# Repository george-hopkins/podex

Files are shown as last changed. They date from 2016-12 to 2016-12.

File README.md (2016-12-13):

# podex

**podex** is an AVR-based BDM interface for 68HC12 processors.

## Documentation

 * [Introduction](./docs/introduction.md)
 * [Hardware](./docs/hardware.md)
 * [Debugging with GDB](./docs/gdb.md)
 * [Demo Application](./docs/demo.md)
 * [FAQ](./docs/faq.md)

## Authors

 * Marek Peca <marek@duch.cz>

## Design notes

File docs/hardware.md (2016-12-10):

# Hardware

## Schematics

To connect a wire on one side and RS232 on the other to the MCU is almost as difficult as to connect a bulb to battery in a torch.

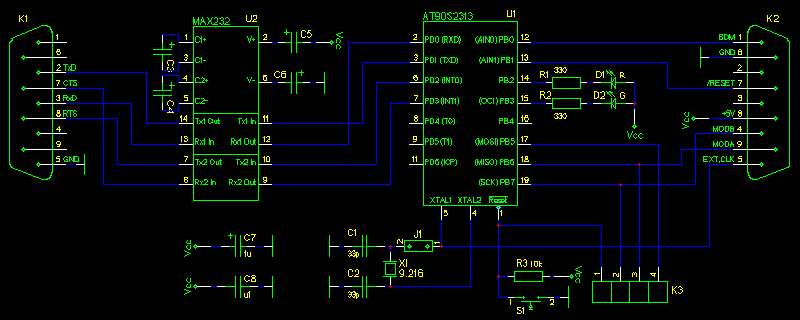
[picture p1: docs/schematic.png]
Schematic


RS232 signals TxD, RxD, RTS, CTS (in schematics marked from podex' point of view) are connected to AVR MCU via buffer U2, MAX232. In prototype, there has been used "worse" variant MAX232 (no A suffix), which may require 1uF capacitors around it (on PCB the size 1206 was chosen). They can be tantalum, but they are also available in ceramic with this capacity (wow, that progress... on Taiwan they are really working hard). Connector K1 can be plugged directly to the COM-port of IBM PC. LEDs D1, D2 acts as indicators of activity and error state and also can be controlled by software of control computer. There are signals MOSI, MISO and SCK of serial programming interface of AVR and its /RESET signal available on connector K3, which serve (together with GND potential from K1 or K2) as an interface for programming FLASH of AVR by podex firmware. PCB allows connecting a switch S1 for resetting AVR, but this shouldn't be needed. Clock for AVR is obtained from crystal X1 with the most desirable frequency of 9.216MHz -- maximal supported rate for 5V AT90S2313 is 10MHz and 9.216MHz is the nearest lower rate, which allows precise division to 115200b/s serial transfer. Crystal is connected through point J1, which should be disconnected and then get clock from external source via connector K2, for example from EClock signal of HC12 CPU. Connector K2 is to be connected to BDM, and among this external clock contains three-state signal BDM(BKGD), signal /RESET and software controlled lines MODA, MODB, allowing use of extended memory (bus) of HC12 CPU.

## Construction

Podex has been designed on two-sided PCB with SMD components mounted on both sides. The most narrow distance between conductors is ca. 0.2mm, but some very kind people at [one PCB laboratory](www.fm.tul.cz/en/departmens/institute-of-information-technology-and-electronics/structure/pcb-lab), which officialy supports only spaces greater than 0.25mm, made boards of podex in a perfect quality. Board has to be put to a cover of two connectors Canon DB9. It is placed between pins of these connectors and surface soldered to these pins (which are ordinary used for soldering with cable wires). Connectors are used this way to hold a board in position. Connector K1 is female, according to RS232 connection, K2 is male to avoid their swapping. LEDs are round with 3mm diameter, if they will be used, it would be very nice to drill holes for them in a cover. As a programming connector K3 I have used SIL (single-in-line) sockets, available as a line, which can be broken to smaller pieces. Pay attention for this component not to be too much thick to fit in a cover. J1 can be hardly connected by a wire, if you won't use external clock (otherwise, let it disconnected). You will probably never need a S1 switch. If you can't use PCB of this layout or you can't order fabrication of it, you can build the circuit on a universal PCB -- it is very simple.

### Printed Circuit Board

#### PCB (Top Layer)

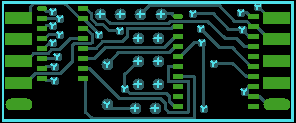
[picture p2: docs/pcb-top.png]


#### PCB (Bottom Layer)

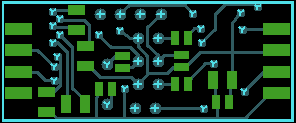
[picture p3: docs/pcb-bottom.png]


#### Components (Top Layer)

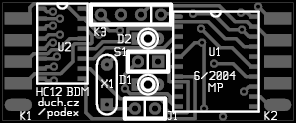
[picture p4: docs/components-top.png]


#### Components (Bottom Layer)

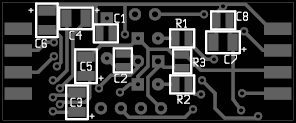
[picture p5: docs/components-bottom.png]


### List of Components

| Parts | Description | Package | Value |
|---|---|---|---|
| U1 | AT90S2313 | SO20W | |
| U2 | MAX232 | SO16 | |
| K1, K2 | DB9 | DB9SM | |
| D1 | LED | LED_3mm | R |
| D2 | LED | LED_3mm | G |
| C1, C2 | CAPACITOR | 0805 | 33p |
| C8 | CAPACITOR | 0805 | u1 |
| R1, R2 | RESISTOR | 0805 | 330 |
| R3 | RESISTOR | 805 | 10k |
| S1 | SWITCH_PUSHBUTTON_NO | JUMPER2 | |
| X1 | CRYSTAL | HC49 | 9.216MHz |
| J1 | JUMPER | JUMPER2 | |
| C3, C4, C5, C6, C7 | CAPACITOR | 1206 | 1u |
| K3 | HEADER3 | JUMPER4 | |

Podex box is connected to control computer by direct plugging it to RS232 DB9 connector or by a cable, which must contain signals RTS and CTS. For BDM interface, there is a standardized 6pin connector, recommended by HC12 documentation, for use of lines MODA, MODB there is its 10pin extension. Pinout of K2 connector is chosen to allow direct interconnection of self-cutting DB9 connector on the podex side and 6(10)pin self-cutting connector PFL on the other side of AWG cable.

BDM connectors connection

## Firmware Flashing

Firmware is loaded to FLASH of AVR AT90S2313 via connector K3. For this it is sufficient to connect serial programming interface signals to parallel interface LPT/Centronics according to following schematic, widely used in AVR community and known as a "Direct AVR Parallel Access":

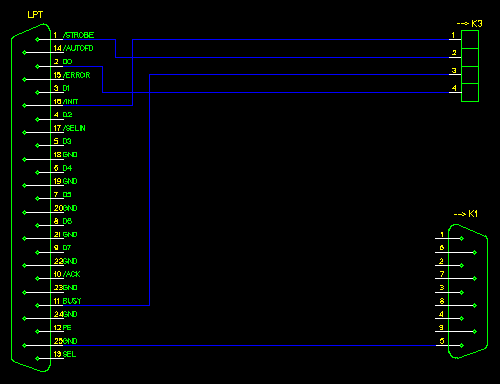
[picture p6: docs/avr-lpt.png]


Attention, there should be also connected a ground of podex (GND) to a control computer during programing, using a connector K1. Also it is needed to power flashed podex by 5V source via K2 connector (it is possible to power it from a HC12 board, if there aren't used lines MODA, MODB).

With above mentioned parallel port connection there can be used e.g. flashing software [uisp](http://www.nongnu.org/uisp/). The firmware is then loaded e.g. by the following command:

```bash
uisp -dlpt=0x378 -dprog=dapa --erase --upload --verify if=podex.hex -v=3 --hash=12
```

(0x378 is LPT base address, podex.hex is filename of the firmware, for more see uisp docs.) After loading of firmware the podex is finished and ready to operate with HC12.

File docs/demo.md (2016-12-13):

# Demo Application

As a very little demonstration of podex use, a small program in C is included which displays eightbit moving light ("snake"), and guide how to compile it, load to RAM or FLASH and debug. The program expects that there are eight lights connected to port PH (switched on by level H). It has been tested on a board with M68HC912D60A.

At the beggining, source includes definition file `intvec.h`, where is defined data structure interrupt_vectors, copied from [a post](https://groups.yahoo.com/neo/groups/gnu-m68hc11/conversations/topics/4010) in a mailing list. Only one entry in this structure is used -- start of the program (`_start` is the very beggining of compiled program). If the program would use some interrupt handlers, their names should be added to this structure. This structure is inserted to a linker section called `.vectors`, which is on the end of memory address space, starting with address 0xff00, where HC12 looks for hardware event handler pointers. Who knows GNU ld well, he will perhaps find my strange solution fool, so, please, excuse me.

Follow a definition of I/O space constant pointers DDRH and PORTH, ie. control registers of output port, which has to be attached to lights. Function `sleep()` does a delay by thousands repetitions of nothing to get a speed of snake's motion reasonable. The eternal loop of main program contains no magic, only a very weird expression of rotation of eight bits, which isn't (at least in current version) optimized to a rotation instruction by gcc, what a wonder, gcc places this ugly thing in output verbatim. If anybody suffers from this, there is no problem to insert a piece of assembler in source.

In the case of execution from FLASH (ie. automatically after reset or power on) there is redefined the `__premain` function, which is called before first function call, so it means before call of `main()`. In this function, there is on the first place disabled an evil watchdog COP, because some HC12's are buggy and need this to not to be stopped by it. But mainly, there is remapped RAM memory from original location at 0x000 (which isn't very handy, because it's overlapped with control registers) to new address 0x800 and then the stack pointer is moved by the same distance to point to newly located RAM and not to the hole at old location.

Linker ld should know, in which address range should the result reside, it is possible to specify this by a so called ld-script. For operation with RAM only, there has been created script `ram.x`, for placement of program to FLASH there is a script `flash.x`. Compilation is exeuted using Makefile.

If you want the program to be in FLASH, to be run automatically after HC12 reset, you can execute:

```bash
make FLASH=
m68hc12-gdb snake.elf
# (gdb) target bdm12 ttyS0 4 0x0 0x800 0xd00 0x8000
# (gdb) load snake.elf
```

If you'd like to load the program to RAM and debug it a little bit, you can execute:

```bash
make
m68hc12-gdb snake.elf
# (gdb) target bdm12 ...
```

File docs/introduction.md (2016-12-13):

# Introduction

## What is BDM of Motorola HC12?

BDM (background debugging mode) of Motorola 68HC12 processors is

 * special CPU mode, in which is possible to intervene in a program execution, to read and write memory and registers, debug the program (set breakpoints, watchpoints, step)
 * interface of HC12 CPU, which is used to control BDM mode (from another computer)

The BDM interface is used either for HC12 microcontroller program debugging as for programming of their FLASH memories. BDM is the most convenient way to program internal FLASH memory of HC12, but it is also able to program external memories, which are found eg. on some development boards.

BDM, used in Motorola HC12 CPU's, is implemented only in this processor family. There is a different interface, called also BDM, and offering similar functionality, implemented in Motorola 32bit MCU series 68300. Other similar, but more general interface, used by many vendors either for processors and microcontrollers, as in programmable logic devices and memories, is JTAG.

## What is podex (BDM pod)?

Our podex is an interface (physical, ie. a box, circuit -- called "pod"), interconnecting BDM of HC12 CPU with another computer, from which is the HC12 programmed and debugged. One side of podex is connected to BDM interface (standard 6pin or extended 10pin connector) and other side of podex to RS232 serial interface of control computer. It also works well with USB-RS232 converter and should work also with other computers, than Intel/IBM PC.

Schematics, directions for assembly and use, firmware for MCU contained in podex, are here offered for free public use. Cost of components (at least in the Czech republic, but they are anyway all manufactured in Asia) is about 5EUR (and it's still dropping...).

In a stage of podex development, I have heard of only two pods, which have had schematics publicly available:

 * Malte Avenhuse's pod, which creator also have published its firmware of MCU; this pod, however, isn't supported by any debugger
 * Kevin Ross' pod, which is commercial, but sold as a kit; it was the only pod beside Malte Avenhaus', which has had published a communication protocol and which is also supported by two commercial debuggers and by GNU gdb

Podex has been designed to be protocol-compatible with pod of Kevin Ross. The main goal was to develop a cheap and freely available BDM pod, which will be able to operate with GNU gdb debugger. I consider it's better to implement the Kevin Ross' protocol (even it's somehow thick-skulled), for which is GNU gdb already ported (and to improve this port and profit from wider user base), than to invent another, functionally the same, protocol, and put redundant support code for almost the same thing to gdb.

Podex interconnects one-wire bidirectional BDM interface (which requires pretty precise timing and so it cannot be implemented only in software without keeping some important time delays exact) with serial line of control computer. The main part of communication on the line is only passed over by pode between serial line and BDM, the rest of communication on the side of control computer are some service commands, such as time constant of BDM setting (according to HC12 frequency) or controlling of HC12 RESET line, also connected to podex. Podex is based on Atmel AVR MCU, in presented circuit with particular AT90S2313. Use of MCU as a BDM interface controller (as opposite to eg. gate array) implies, unfortunately, the BDM interface speed limit (what means limit of connected HC12's frequency).

## Where can I use podex?

Podex is able to operate with BDM of all microcomputers, boards and devices, based on Motorola HC12 or HCS12 core, which have

 * frequency of BDM (which is a half of clock rate) up to approximately the frequency of used AVR in podex; in presented circuit with 9.216MHz crystal it can operate with HC12 clocked up to cca 18..22MHz
 * power supply voltage 5V (the same as voltage supply of used AVR MCU); maybe in the future I can try to assemble a converter to 3V, another solution could be to use 3V AVR (but on the other hand, they use to be slower)

Podex operates with following debuggers:

 * [GNU gdb](https://www.gnu.org/software/gdb/) -- the main supported debugger (and IMHO the best debugger of all), it can be used together with [GNU m68hc1x toolsuite](https://www.gnu.org/software/m68hc11/), including binutils and GCC
 * [NoICE Debugger](http://www.noicedebugger.com/help/bdm12.htm)
 * [StingRay 68HC12 debugger](http://www.softtools.com/stingray_bdm12_features.htm) by Sid Prince

## How could it be done better?

Podex has been developped due to immediate need of a BDM pod in period of about two months (we didn't want t pay for expensive debuggers, especially when there are many people at our departments, who probably will found such BDM pods useful). The main goal was a low cost, easy construction and immediate application (with support of GNU gdb). It isn't, however, a state of the art solution, neither an original or inconquerable device. For an advice, I try to write down some ways of better solution or improvements:

 * faster podex MCU -- somebody, who needs to work with a faster rated HC12's, can try to use a faster AVR MCU in the circuit -- it is only necessary to change one timing constant in firmware source code (and, probably, a PCB layout)
 * direct use of USB -- surely, there could be used a MCU with direct support of USB (or with some external controller) and profit from a faster communication between MCU and control computer and for greater convenience of use with computers, offering USB and lacking a serial port; but in podex design I preferred to use a serial port for its widest support everywhere (asynchronous serial transfer with start and stopbits since end of 19th century), which also means it can be easily connected to USB via converter (while, you know, it's very difficult to connect USB device to serial port); on the other hand, it could be very interresting to connect BDM interface to USB controller without use of MCU, eg. to FT2232C with programmable synchronous serial port -- but I haven't been thinking about this
 * application of programmable serial interface controller -- there are some universal circuits, which should be able to be connected to BDM interface after appropriate setup; these controllers are part of some MCU's (Hitachi)
 * use of programmable gate array -- IMHO the most interresting way, allowing the highest speed of BDM; it should be enough to implement in gate array sending and receiving of one bit over BDM (it is done in 16 clock periods), for this purpose it should be sufficient to use a really little array (GAL22V10?); gate array would be then connected to parallel port (Centronics-LPT) or USB converter (FT245, FT2232C) -- if I will find someday somewere a piece of free time, I'd like to try this way of implementing BDM and try to add a support to GNU gdb, having the most of support code common to podex and gate array
 * support of more interfaces (BDM of other CPU's, JTAG) -- it is really wonderful to have a universal device for programming and debugging of wide range of processors and other devices, than to be limited only to HC12 series; but podex is designed to be and will remain tiny and cheap tool for HC12 -- those, who need greater solution, will find it somewhere else (hope, that soon)

### Related Projects

 * [Free AVR ICE / GDB-Serializer](http://savannah.nongnu.org/projects/freeice) (for AVR (with JTAG), arm7/9 (JTAG), 68HC08, 683xx, 68HC16, 68HC12, coldfire)
 * [BDM/GDB for 683xx](http://cmp.felk.cvut.cz/~pisa/m683xx/bdm_driver.html) by Pavel Píša
 * [BDM implementation in a gate array](http://micro.feld.cvut.cz/~rozehnal/) by Zdeněk Rozehnal
 * [BDM12](http://www.kevinro.com/bdm12.pdf) by Kevin Ross -- pod, with which we would like to be compatible
 * [BDM](http://www.avenhaus.de/Malte/BDM12/) by Malte Avenhaus -- as we know, the first author of BDM with publicly available sources

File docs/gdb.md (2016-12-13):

# Debugging with GDB

Podex is able to operate with the excellent GNU debugger GDB. GDB can be used with podex to load a code to RAM and FLASH memories of HC12, to run and step programs in them, to use breakpoints etc. while working at level of assembler as well as on a higher language (C) source level. I worked in gdb in cooperation with 68HC1x branche of GNU gcc and binutils, but GNU gdb should principially work with output of other compillers as well. There are supported formats such as ELF, S-record, headerless binary and others contained in bfd library, for source-level debugging there is used format stabs (and maybe also others).

## How to obtain GDB for podex?

GDB port for Kevin Ross' BDM12 protocol has been added to 68HC1x branch of gdb by Timothy Housel. While podex was in a development stage (April 2004), there were available 68HC1x patch for gdb-6.0 marked 20040222 ([gdb-6.0.tar.gz](http://ftp.gnu.org/pub/gnu/gdb/gdb-6.0.tar.gz), [m68hc1x-builder-2.91.tar.gz](http://m68hc11.serveftp.org/m68hc1x-builder-2.91.tar.gz)). I suggest also to apply another little patch for BDM12 support code in gdb, which corrects one race-condition bug and also enlarges some timeout constants, what has been found necessary, especially while working with USB-RS232 converter or on heavy loaded machines. (Patch haven't been merged with a 68HC1x branch yet, so it can be downloaded [here](gdb-bdm12-mp.diff).)

GNU gdb is in philosophy a unix application, but BDM12 port, what means its code for acces to RTS, CTS lines of serial port, is written to be compatible with unix-like GNU environment Cygwin32/Mingw32 for the poor ugly operating chaos M$ Windows. To compile gdb, download mentioned sources: official source GNU `gdb-6.0.tar.gz`, M68HC1x branch `m68hc1x-builder-2.91.tar.gz` and a patch `gdb-bdm12-mp.diff`. Then unpack, patch and make:

```bash
tar xzvf gdb-6.0.tar.gz
tar xzvf m68hc1x-builder-2.91.tar.gz
cd gdb-6.0
patch -p1 < ../m68hc1x-builder-2.91/gdb-6.0-m68hc1x-20040222.diffs
patch -p1 < ../gdb-bdm12-mp.diff

./configure --target=m68hc11-elf --program-prefix=m68hc12-
make
#optionally with root privileges do a make install (by defult to /usr/local/...)
```

I suggest also to install a 68HC1x GNU tools gcc and binutils (including the gas assembler). They are often available as precompiled packages in many GNU operating system distributions (eg. Debian Linux), what can save yourself from the bloody compilation.

## Basic use of gdb with podex

Operation with podex in gdb is introduced by command target bdm12:

```text
(gdb) target bdm12
Usage: target bdm12 <serial_device> <E-clock rate (1,2,4, or 8 MHz)>
                            <register base> <ram base> <eeprom base> <flash base>
(ex. target bdm12 com1 8 0x0 0x800 0xd00 0x8000 on Win32,
   or target bdm12 ttya 8 0x0 0x800 0xd00 0x8000 on UNIX)
```

Where `serial_device` is a name of the serial device, which is podex attched to, what can be in Linux eg. ttyS? for ordinary COM-port or ttyUSB? in case of USB converter. Attention, in current version of BDM12 port under unix there is contatenated prefix "/dev/" to the name of device -- this saves your fingers of typing of 5 characters, but it is restrictive and not very clever and it should be as soon as possible put away from the code. `E-clock_rate` is a frequency of BDM bus of target HC12, but in current version it is restricted to 4 integer values, because it uses only `SetParam` firmware command (I hope we'll very soon add support for arbitrary rated HC12's using `ExtendedSpeed` firmware command).

Argument `register_base` tells podex, that registers will be moved somewhere, see `SetRegisterBase` firmware command. Arguments `ram_base`, `eeprom_base` and `flash_base` gives information about location of internal memories, ie. 2KB RAM, 32KB FLASH and 768B EEPROM. It is not clear to me, how to solve complicated cases of numerous different configurations of external memories of different types (RAM, FLASH) connected to HC12 -- maybe it would be fine to look to more mature ports of gdb code for other processors for inspiration (if they exist and solve it).

If we want to debug a code from binary file, which contains debugging information (function and variable names -- labels, numbers of lines in source), we can supply its name as an argument when starting gdb or later by a file command.

Program code is loaded to HC12 CPU by a load command (large data segments can probably by a restore command, but I haven't used it). This is a most important and also a most complicated task for gdb with podex. Program (data) can be loaded either in RAM, but also to EEPROM and mainly to FLASH, which is programmed by gdb via podex according to a proedure, described later. This way, gdb can be used as an internal HC12 FLASH memory programmer. Properties and problems of FLASH memory programming are described in next section.

After program is placed in some of HC12's memories, in the simplest case in RAM, it can be runned, stepped, stopped and tortured in any manner. Breakpoints can be set by a `break` command, on a line number level (`break 33` or `break apollo_jets.c:1811`), function name (`break speed_up`) or memory address (`break *0x8a0d`). Program is started by a `run` command, then it can be interrupted by pressing Ctrl-C. Execution can be then resumed by `continue` command, stepped by commands `step` (including diving to inner functions), `next` (to the next source line), `until` etc. on the source level, and on the machine instruction level by `stepi`, `nexti` (`nexti` similarly doesn't dive to subroutine calls).

GDB also allows to mess with HC12 registers and memory, contents of all (and there is really a lot of them at HC12) registers can be dumped with a `regs` command, writing to them is done by a set command (`set $d=-1977, set $pc=0x8000`), which can also write to a memory, as well as to a variable (`set rpm=0`) or arbitrary address (`set *0x804=0xbeef`). Maybe, there could probably work also writing to a FLASH, but I'm not sure, if current BDM12 port won't damage RAM contents. To read single registers, variables or memory, there can be used a `print` command (`print $x`, `print gear_box->wheel[5]`, `print *0x806`). To read from certain memory addresses, there is a useful command `x` (examine), which can show value in many different number bases and of arbitrary bit size (`x/b *0x808` will show byte from the address, `x/h *0x808` will show 16bit word from that address). If you will get a suspicion or paranoia, which can easily happen while debugging, you can dump the instructions within a function or a memory region by disassemble command (`disassemble _start`, `disassemble slow_down`, `disassemble 0x802c 0x8100`, without argument will disassemble the function, in which currently executed code of HC12 is).

GNU gdb is a mighty beast, so for discovering possibilities of its use with podex or without it, consult gdb command help | trying out | documentation | sources reading. Have a fun!

GNU gdb BDM12 (ie. podex) support code by Tim Housel is placed mainly in `bdm12.c` file, constant definitions and declarations are in `bdm12.h` file, this is glued with main program of gdb by `remote-bdm12.c` file. For FLASH programming purposes, there are files `bdm12_eraseflash.h` and `bdm12_programflash.h`.

## Flash memory programming

HC12 internal FLASH memories are accessed for reading in an ordinary manner, the same as RAM and EEPROM is read, either by any machine code instruction or using BDM commands READ_BYTE, READ_WORD. But for writing to internal FLASH it is needed to traffic a bit with HC12 control registers and to satisfy timing, as well as with EEPROM. But, in opposite, FLASH cannot be programmed directly by BDM write commands (to control registers and memory). To write to internal FLASH memories of HC12, there must be a program (routine) loaded to HC12 RAM, which will do FLASH writing operation.

There is a problem, that programmer's models of internal memories of different HC12 types is also different and probably there cannot be one universal routine, which could write to FLASH memories of all of HC12 variants. One man from Motorola assured me, that in HCS12 series they have advanced and there will be applied the same programmer's model for all FLASH memories in HCS12. Well, it seems that evolution goes sometimes not only backward, as from hand-axe to cellular phone. On the other hand, there will always remain wide set of different development boards with external FLASH memories, so if we would like to program them via BDM also, we will need appropriate routine for each of them.

HC12 FLASH programming is done in following steps: first, there is loaded an erasing program to RAM, and by its execution, entire FLASH is erased. Then, there is loaded a writing program to RAM, and into the free rest of RAM, there is always put a block of data, which is then, after passing information about target block position in FLASH and block length, programmed into the FLASH. Execution of writing program is repeated for each next block, until entire data are programmed into FLASH. Loading of erasing and writing routines to RAM, their execution and passing of parameters (by register or memory location) is done via BDM, after finishing execution of routines, they use to issue a BGND instruction, what is also detected by BDM. There is also necessary to tell to programs about timing, because it is derived from HC12 clock.

## Flash and GDB

Current support of HC12 FLASHing in gdb is in a dismal state. Tim Housel filled bdm12_eraseflash.h and bdm12_programflash.h files by routines for programming M68HC12B32 family FLASH, moreover, containing fixed timing constant, see their sourcecode. So, probably, this source is able to successfuly program only FLASH memories of HC12B32 with 16MHz crystal frequency.

How to overcome? The best solution would be to have

 * unified program interface for execution of erasing and writing routines, ie. defined calling, perhaps relocation, parameter passing -- containing target and maybe also source address, data block length and CPU frequency
 * set (a lots of) erasing and writing routines dynamically loadable from a file, external to gdb, allowing the user to supply own routines

Such solution is implemented for example by [P&E for HC12](http://www.pemicro.com/support/flash_list_menu.cfm), [Pavel Píša for M683xx](http://cmp.felk.cvut.cz/~pisa/m683xx/bdm_driver.html). There is a question, which format to choose for external loadable routines, maybe it would be fine to use ELF, which already solves symbol names and relocation -- but on the other hand, it is a complex beast and from other point of view, the simplicity of headerless binary file is really beautiful... Furthermore, it would be also desirable to look to some other parts of gdb, if there is dynamical loading of some kind of modules already solved in gdb, for efforts to be unified. I would like to live to see such flexible and efficient support of HC12 FLASHing in gdb and I would also like, if I will have a time, to help with it a bit, but now I'm heavily occupied, so I hope somebody else will join the task.

As a temporary solution, there could be defined a simple head(er)less interface, similar to code of Tim Housel, where would be defined memory offsets of necessary argument and maybe there could be also supplied some skeleton of program in assembler or GNU C (with delay loop in assembler), to help users to supply their particular routines for their specific HC12 confgurations, and also to extend current code of passing of a HC12 CPU frequency (timing) argument.

What to do, if you need with current state of gdb port to use a FLASH with your flavour of HC12? I have been in the same case, when I had to prepare for my colleague support for internal FLASH of M68HC12D60A, at least its upper 32KB bank. With the minimal effort, or in other words, with minimum intervention to gdb code and within minimal time, I have only replaced support code for HC12B32 in bdm12_*flash.h by the code for HC12D60A.

For the educational and inquisitive reasons, I haven't wrote the code by myself, but rather used freely downloadable routines from P&E server. The main goal of this was to speculate, whether it would be good in the future (hope it will come) support of dynamically loadable modules to use the same or similar philosophy, as our predecessors did. If it will be allowed by your conscience and by the law of your country, you will see, that these are in fact S-records, enriched by a header with some initial setup of some registers; this header can be deleted and then cruelly disassembled by `m68hc12-objdump -mm68hc12 -D something.sx`. If you need it quickly and only for personal use, I hope, that nobody will be angry at you about that.

## Incorporating your own programming routine in the current (poor) code of GDB

I will describe a recipe, by which I added a support (as a temporary solution, but you know, that temporary solutions are immortal) for erasing and writing to 32KB FLASH of HC12D60A.

 * Create your own flashing program, probably in assembler, but it should make sense to do it in C also (I'd like to put here some example); programming algorithm (what to write to which control registers and how many microseconds to sleep between) is described in datasheet of particular HC12 (eg. for D60A it is on page 102 of the [datasheet](http://www.nxp.com/assets/documents/data/en/data-sheets/MC68HC912D60A.pdf)), or sometimes in an application note (for D60A it is [AN2166](http://www.nxp.com/assets/documents/data/en/application-notes/AN2166.pdf))
 * Take a look at `gdb/blesk.s` to see how such a program might look like. Note: I was too lazy to divide the code to erasing and flashing part, so I left it in one block, even it's true, that erase part occupies a space in RAM.
 * Compile the program -- I don't know why, but I haven't succeeded with generation of binary incarnation of a code, located in RAM from address 0x800, with GNU assembler gas and binutils -- after conversion by objcopy it filled address fields with nonsense zeroes (you must excuse my inability to work with GNU tools).
   - Solution, even it is a pity: Use the assembler [ASM12](https://www.mgtek.com/miniide/) from MGTEK. Convert the code using `gas2mtek.pl` to comply with the slightly different syntax.
 * Make a constant (global variable) in a header file `bdm*flash.h` from the compiled program. I did it using `gdb/mpconvert.c` (see original convert.c in Tim Housel's comment) and the Makefile in the same directory. The resulting header file is then, in my lazy case, included to both bdm12_program and eraseflash.h

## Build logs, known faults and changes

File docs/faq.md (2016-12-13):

# FAQ

#### After few hours of Internet search, I have found about 20 BDM pods available. Why are you trying to augment existing chaos by another pod?

In present time (2004), I haven't found any BDM interface with freely available construction plans, ie. schematics and eventually a firmware, other than pod of [Malte Avenhaus](http://www.avenhaus.de/Malte/BDM12/), which, however, could be used only after much stronger effort (to write a support to debugger), than contruction of whole podex.

#### Why did you copy Kevin Ross' protocol? Don't you think it is morally wrong?

By all means it is better to use existing, although a bit dumb, protocol, if it is sufficient, than to plague the world with another incompatible pod, moreover, to add another support code to gdb for the very same, only camouflaged thing -- to waste efforts to write a debugger port, debug the debugger... By all means it is better to unify with existing gdb port and to try to improve this port, which will help users of both pods.

This solution also means to be supported by other debuggers, which supports Kevin Ross for a long time. I don't think, it is immoral, I haven't stole anything of Kevin Ross, I haven't ever seen his BDM pod, neither his debugger db12.exe. Anyway, many thanks to him for publishing his communication protocol.

#### Why have you used AVR MCU? Why not HC08, HC11, HC(S)12? Why not PIC,...?

AVR processors are cheap and little, they have very nice and consistent assembler, they aren't so fancy, as messy family of PIC, they have great and effective support of GNU tools. Firmware of podex isn't fixed to any specific AVR model, it works with AT90S2313 (well, not very fresh meat...), so it will work in other AVR as well.

#### Where can I buy podex? How much does it cost?

You cannot (at least at this moment). Podex is a construction plan published for free use. I don't know, if I would like somebody to sell it -- if you are interrested in production of PCB's, selling components or final pods, let me mail, we can think about it.

#### What is podex able to? Which debuggers are able to work with?

Podex can program and debug processors of Motorola 68HC12 and HCS12 family, at this moment operating at 5V voltage and crystal frequency up to cca 20MHz, maybe also a higher. Podex is intended to be used with debugger GNU gdb, but it should work also with NoICE and StingRay.

#### What isn't podex able to?

To work with processors, other than HC(S)12 family, with other interfaces, than their BDM. Podex doesn't know JTAG, podex won't talk with HC08, HC11, neither M68300, neither with your mother-in-law...

#### Why writing to my FLASH doesn't work?

Are you using gdb? If you are, then make sure, you have a correct routines for erasing and writing to FLASH. Are you using some another debugger? Mail to the vendor, your podex is OK.

#### When trying to connect with gdb to target bdm12, I get a communication error (bdm12_put_packet RTS1->CTS1: Couldn't communicate with BDM12 pod)

Do you have podex plugged directly into a serial port? If not, does your serial cable have wires even for both signals RTS and CTS? Are you trying to connect to right port? In a hopeless case, you can try to enlarge timeout constants in `bdm12.h`, if you think your computer/bus is running out of resources.

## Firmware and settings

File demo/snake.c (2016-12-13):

#ifdef FLASH
#include "intvec.h"

extern void _start();

#define FFFF_VEC ((interrupt_t) 0xffff)
struct interrupt_vectors __attribute__((section(".vectors"))) vectors = {
  FFFF_VEC, FFFF_VEC, FFFF_VEC, FFFF_VEC, FFFF_VEC, FFFF_VEC, FFFF_VEC, FFFF_VEC,
  FFFF_VEC, FFFF_VEC, FFFF_VEC, FFFF_VEC, FFFF_VEC, FFFF_VEC, FFFF_VEC, FFFF_VEC,
  FFFF_VEC, FFFF_VEC, FFFF_VEC, FFFF_VEC, FFFF_VEC, FFFF_VEC, FFFF_VEC, FFFF_VEC,
  FFFF_VEC, FFFF_VEC, FFFF_VEC, FFFF_VEC, FFFF_VEC, FFFF_VEC, FFFF_VEC,
  reset_handler: _start
};
#endif

#define IO_BASE 0
#define PORTH *(volatile unsigned char *)(IO_BASE + 0x29)
#define DDRH *(volatile unsigned char *)(IO_BASE + 0x2b)

#define SLEEP_N 30000
void sleep() {
  unsigned i;
  for (i = 0; i < SLEEP_N; i++);
}

main() {
  unsigned char b = 0x07;
  DDRH = 0xff;
  for (;;) {
    PORTH = b;
    sleep();
    b = (b<<1)|(b>>7);
  }
}

#ifdef FLASH
void __premain() {
  /* zrusit COPCTL */
  __asm__ __volatile__("clr 0x16");
  /* locate RAM at 0x800..0x9ff */
  __asm__ __volatile__("movb #0x08, 0x10");
  /* update stack pointer */
  __asm__ __volatile__("tfr sp, d");
  __asm__ __volatile__("addd #0x800");
  __asm__ __volatile__("tfr d, sp");
}
#endif

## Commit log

2016-12-10 Import firmware
    Source: http://mini-cooper-clubman.de/download/podex.hex
2016-12-13 Import PCB files
    Source: http://www.duch.cz/podex/hw/podex_pcb.zip
    Source: http://www.duch.cz/podex/hw/podex_pcb_eps.zip
    [podex_back.gbr, podex_backmask.gbr, podex_backpaste.gbr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]
